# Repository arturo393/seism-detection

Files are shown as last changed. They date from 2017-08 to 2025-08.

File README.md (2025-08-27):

# Sistema de Detección de Sismos

Un sistema de detección de terremotos basado en acelerómetros que utiliza algoritmos avanzados de procesamiento de señales para detectar eventos sísmicos en tiempo real.

## 📋 Descripción

Este proyecto implementa un sistema completo de detección sísmica que procesa datos de acelerómetros utilizando parámetros como IQR (Rango Intercuartílico), CAV (Vector Acelerativo Acumulativo), RSL (Relación de Señal) y ZC (Cruces por Cero) para identificar eventos sísmicos.

### Características principales

- **Detección en tiempo real** de eventos sísmicos
- **Múltiples plataformas**: ESP8266 (v1) y Particle Photon (v2)
- **Soporte para múltiples acelerómetros**
- **Conectividad WiFi** para envío de datos
- **Georeferenciación** automática de eventos
- **Análisis de datos** con herramientas Python
- **Configuración remota** de parámetros

## 🏗️ Arquitectura del Sistema

### Versión 1 (ESP8266)
- **Microcontrolador**: NodeMCU 1.0 (ESP8266)
- **Ubicación**: `/prosismic/`
- **Acelerómetros soportados**:
  - SparkFun Triple Axis Accelerometer Breakout - MMA8452Q
  - MinIMU-9 v2 (L3GD20 y LSM303DLHC)
  - SparkFun Triple Axis Accelerometer Breakout - ADXL345
  - Módulo GY-291 ADXL345

### Versión 2 (Particle Photon)
- **Microcontrolador**: Particle Photon
- **Ubicación**: `/q_up/`
- **Acelerómetro**: MinIMU-V5 con LIS3MDL
- **Mejoras**: Configuración remota, mejor conectividad

## 🛠️ Instalación y Configuración

### Prerrequisitos

#### Para Versión 1 (ESP8266)
- Arduino IDE con soporte ESP8266
- Librerías necesarias (ver sección de dependencias)

#### Para Versión 2 (Particle Photon)
- Particle CLI o Particle Web IDE
- Cuenta en Particle Cloud

### Instalación de Dependencias

#### Versión 1 (ESP8266)
```bash
# Instalar soporte ESP8266 en Arduino IDE
# Agregar URL en Preferences: https://github.com/esp8266/Arduino
```

**Librerías requeridas:**
- [Arduino Time Library](https://github.com/PaulStoffregen/Time)
- [ArduinoSort](https://github.com/emilv/ArduinoSort)
- [ArduinoJson](https://github.com/bblanchon/ArduinoJson)
- [WiFi Location](https://github.com/gmag11/ESPWifiLocation)
- [WiFiManager](https://github.com/tzapu/WiFiManager)
- [LSM303 Arduino Library](https://github.com/pololu/lsm303-arduino)
- [SparkFun MMA8452Q Library](https://github.com/sparkfun/SparkFun_MMA8452Q_Arduino_Library)
- [Arduino-ADXL345](https://github.com/jarzebski/Arduino-ADXL345)

#### Versión 2 (Particle Photon)
```bash
# Instalar Particle CLI
npm install -g particle-cli
particle login
```

### Configuración

1. **Configurar WiFi** (Versión 1):
   ```cpp
   #define _SSID "tu_red_wifi"
   #define _NETPASS "tu_contraseña"
   ```

2. **Configurar parámetros de detección**:
   ```cpp
   #define SAMPLES 200           // Número de muestras
   #define Factor_IQR  5.0      // Factor de referencia IQR
   #define Factor_CAV  1.5      // Factor de referencia CAV
   #define Factor_ZC   1        // Factor de referencia ZC
   ```

### Compilación y Carga

#### Versión 1 (ESP8266)
```bash
cd prosismic/prosismic/
# Abrir prosismic.ino en Arduino IDE
# Seleccionar board: NodeMCU 1.0 (ESP-12E Module)
# Compilar y cargar
```

#### Versión 2 (Particle Photon)
```bash
cd q_up/
particle compile photon
particle flash [device_name] firmware.bin
```

## 🚀 Uso

### Parámetros de Detección

El sistema utiliza los siguientes parámetros para detectar eventos sísmicos:

- **IQR (Interquartile Range)**: Mide la variabilidad de la señal
- **CAV (Cumulative Absolute Velocity)**: Acumulación de velocidad absoluta
- **RSL (Response Spectrum Level)**: Nivel del espectro de respuesta
- **ZC (Zero Crossings)**: Cruces por cero de la señal

### Salida de Datos

El sistema genera datos en formato serie con el siguiente formato:
```
Date Time(hh:mm:ss:mss) Sample x y z NetAcc xMax yMax zMax NetAccMax t_NetAccMax ZC IQR CAV RSL

22/6/2017 21:22:36.673    68 0 -2 -2 282  3 6 3 6 608 673 26 103 200 111
22/6/2017 21:22:36.684    69 0 -1 -2 223  2 6 3 6 608 684 25 103 199 111
```

### Herramientas de Análisis

#### Visualización de datos (Python)
```bash
python acc_plot.py
```

#### Servidor serie para captura de datos
```bash
python serial_server.py
```

## 📁 Estructura del Proyecto

```
seism-detection/
├── prosismic/           # Versión 1 (ESP8266)
│   ├── prosismic/
│   │   └── prosismic.ino
│   ├── lib/             # Librerías específicas
│   └── platformio.ini
├── q_up/                # Versión 2 (Particle Photon)
│   ├── src/
│   │   └── q_up.ino
│   ├── lib/             # Librerías específicas
│   └── project.properties
├── Case/                # Diseños de carcasa (DXF)
├── Hardware/            # Esquemas electrónicos
├── acc_plot.py          # Herramienta de visualización
├── serial_server.py     # Servidor de captura de datos
└── README.md
```

## 🔧 Configuración Avanzada

### Parámetros Configurables

- `FrecRPS`: Frecuencia de muestreo (Hz)
- `SAMPLES`: Número de muestras para análisis
- `DPTIME`: Tiempo para determinar desplazamiento (ms)
- `MTIME`: Tiempo para determinar movimiento (ms)

### API de Configuración Remota (Versión 2)

La versión 2 permite configuración remota a través de Particle Cloud:
- `setIQR(value)`: Configurar umbral IQR
- `setCAV(value)`: Configurar umbral CAV
- `setRSL(value)`: Configurar umbral RSL
- `setRestartTime(time)`: Configurar tiempo de reinicio

## 🤝 Contribución

¡Las contribuciones son bienvenidas! Por favor lee [CONTRIBUTING.md](CONTRIBUTING.md) para detalles sobre el proceso de contribución.

## 📄 Licencia

Este proyecto está licenciado bajo la Licencia MIT - ver el archivo [LICENSE](LICENSE) para detalles.

## 👨‍💻 Autor

**Arturo Veras** - *Desarrollo inicial* - [arturo393](https://github.com/arturo393)

## 📖 Documentación Adicional

Para más información detallada sobre el funcionamiento del algoritmo, revisar la [Wiki del proyecto](https://github.com/arturo393/seism-detection/wiki).

## 🏷️ Versiones

Ver [CHANGELOG.md](CHANGELOG.md) para una lista de cambios en cada versión.

---

⚡ **Estado del Proyecto**: Activo y en desarrollo continuo

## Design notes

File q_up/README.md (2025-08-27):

# Seismic Detection v2 (Particle Photon)

Sistema de detección de sismos basado en Particle Photon con acelerómetro MinIMU-V5.

## 📋 Descripción

Esta es la **Versión 2** del sistema de detección sísmica, que utiliza la plataforma Particle Photon para mejorar la conectividad y permitir configuración remota a través de Particle Cloud.

### Características principales
- **Microcontrolador**: Particle Photon
- **Acelerómetro**: MinIMU-V5 con sensor LIS3MDL
- **Conectividad**: WiFi con Particle Cloud
- **Configuración remota**: Parámetros ajustables vía cloud
- **Georeferenciación**: Google Maps Device Locator
- **Frecuencia de muestreo**: 100 Hz configurable

## 🛠️ Instalación

### Prerrequisitos
```bash
# Instalar Particle CLI
npm install -g particle-cli

# Iniciar sesión
particle login
```

### Compilación
```bash
# Compilar para Photon
particle compile photon

# Flashear al dispositivo
particle flash [device_name] firmware.bin
```

## ⚙️ Configuración

### Variables Cloud Disponibles
- `ZCref`: Umbral de cruces por cero
- `IQRref`: Umbral del rango intercuartílico  
- `CAVref`: Umbral del vector acelerativo acumulativo
- `RSLref`: Umbral de relación de señal
- `Latitude`: Latitud del dispositivo
- `Longitude`: Longitud del dispositivo

### Funciones Cloud Disponibles
- `setZC(value)`: Configurar umbral ZC
- `setIQR(value)`: Configurar umbral IQR
- `setCAV(value)`: Configurar umbral CAV
- `setRSL(value)`: Configurar umbral RSL
- `setReferencia(mode)`: Activar/desactivar referencias variables
- `setRestartTime(minutes)`: Configurar tiempo de reinicio
- `setOnlineTime(minutes)`: Configurar tiempo online

## 🔧 Estructura del Proyecto

#### `/src` folder
Contiene el firmware principal del proyecto. El archivo `q_up.ino` implementa:
- Algoritmo de detección sísmica
- Comunicación con Particle Cloud
- Gestión de sensores LSM6
- Sistema de georeferenciación

#### `project.properties` file
Especifica las dependencias de librerías del proyecto:
- LSM6: Comunicación con acelerómetro
- HttpClient: Comunicación HTTP
- google-maps-device-locator: Georeferenciación

#### `/lib` folder
Librerías específicas del proyecto:
- **Filters**: Filtros digitales para procesamiento de señales
- **HttpClient**: Cliente HTTP para Particle
- **LSM6**: Driver para acelerómetro MinIMU-V5

## 📊 Parámetros de Detección

El sistema utiliza cuatro parámetros principales:

| Parámetro | Descripción | Unidad |
|---|---|---|
| **IQR** | Rango Intercuartílico | mg |
| **CAV** | Vector Acelerativo Acumulativo | mg |
| **RSL** | Relación de Señal | % |
| **ZC** | Cruces por Cero | count |

## 🚀 Uso

### Monitoreo en Tiempo Real
```bash
# Ver logs del dispositivo
particle serial monitor

# Ver variables cloud
particle get [device_name] ZCref
particle get [device_name] IQRref
```

### Configuración Remota
```bash
# Configurar umbrales
particle call [device_name] setIQR "500"
particle call [device_name] setCAV "1000"

# Configurar tiempos
particle call [device_name] setRestartTime "10"
```

## 📈 Salida de Datos

El sistema publica eventos al Particle Cloud cuando detecta actividad sísmica:

**Evento**: `Sismo`  
**Formato**: `tiempo;aceleración_max;trigger;ZC;IQR;CAV;RSL;latitud;longitud`

## 🔄 Diferencias con Versión 1

| Aspecto | Versión 1 (ESP8266) | Versión 2 (Photon) |
|---|---|---|
| Microcontrolador | NodeMCU ESP8266 | Particle Photon |
| Acelerómetro | Múltiples (MMA8452Q, LSM303, ADXL345) | MinIMU-V5 (LIS3MDL) |
| Configuración | Hardcoded | Remota vía Cloud |
| Conectividad | WiFi directo | Particle Cloud |
| Georeferenciación | WiFi Location | Google Maps API |

## 📝 Desarrollo

Para agregar archivos adicionales al proyecto, colócalos en la carpeta `/src`. Para librerías externas, crea `/lib/<nombre_libreria>/src` y coloca los archivos `.h` y `.cpp` ahí.

Los archivos que se envían al servicio de compilación incluyen:
- Todo en la carpeta `/src`
- El archivo `project.properties`
- Cualquier librería en `lib/<nombre_libreria>/src`

---

Para más información sobre el proyecto completo, consulta el [README principal](../README.md).

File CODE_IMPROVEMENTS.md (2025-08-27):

# Sugerencias de Mejora del Código

Este documento presenta un análisis del código actual y sugerencias concretas para mejorar la mantenibilidad, eficiencia y estructura del proyecto de detección sísmica.

## 📊 Análisis del Estado Actual

### Estadísticas del Código
- **Versión 1 (ESP8266)**: 1,353 líneas en un solo archivo
- **Versión 2 (Particle)**: 1,130 líneas en un solo archivo
- **Total de archivos .ino**: 22 archivos (incluyendo ejemplos)
- **Librerías duplicadas**: Multiple entre versiones

### Problemas Identificados

#### 1. 🏗️ Estructura Monolítica
**Problema**: Archivos únicos demasiado grandes
```cpp
// prosismic.ino - 1,353 líneas
// q_up.ino - 1,130 líneas
```

**Impacto**:
- Difícil mantenimiento
- Testing complicado
- Colaboración limitada
- Depuración compleja

#### 2. 🌐 Inconsistencia de Nomenclatura
**Problema**: Mezcla de español e inglés
```cpp
// Inconsistente
bool REFERENCIA_VARIABLE = false;
bool DATASEND = true;
int antidesplazamiento();
void printTime();
```

**Impacto**:
- Confusión para desarrolladores
- Dificultad de comprensión
- Mantenimiento complicado

#### 3. 🔒 Configuración Hardcodeada
**Problema**: Credenciales y configuración en código
```cpp
#define _SSID "zekefi-interno"
#define _NETPASS "JtXDF5jK79es"
PRODUCT_ID(6135);
```

**Impacto**:
- Riesgo de seguridad
- Inflexibilidad de configuración
- Dificultad para diferentes entornos

#### 4. 🔄 Código Duplicado
**Problema**: Lógica similar entre versiones
- Algoritmos de detección duplicados
- Librerías repetidas
- Funciones similares reimplementadas

#### 5. 📖 Falta de Documentación
**Problema**: Comentarios insuficientes
```cpp
// Función sin documentación
int antidesplazamiento() {
  // Implementación sin explicación
}
```

## 🛠️ Plan de Mejoras Propuesto

### Fase 1: Restructuración de Archivos

#### 1.1 Modularización del Código

**Estructura propuesta para Versión 1 (ESP8266):**
```
prosismic/
├── src/
│   ├── main.ino              # Función principal y setup
│   ├── seismic_detection.h   # Algoritmos de detección
│   ├── seismic_detection.cpp
│   ├── wifi_manager.h        # Gestión de conectividad
│   ├── wifi_manager.cpp
│   ├── sensor_manager.h      # Gestión de sensores
│   ├── sensor_manager.cpp
│   ├── data_logger.h         # Logging y almacenamiento
│   ├── data_logger.cpp
│   └── config.h              # Configuración y constantes
├── lib/                      # Librerías específicas
├── data/                     # Archivos de configuración
│   └── config.json
└── test/                     # Pruebas unitarias
```

**Estructura propuesta para Versión 2 (Particle):**
```
q_up/
├── src/
│   ├── main.cpp              # Función principal
│   ├── seismic_core.h        # Core del algoritmo
│   ├── seismic_core.cpp
│   ├── cloud_manager.h       # Gestión de Particle Cloud
│   ├── cloud_manager.cpp
│   ├── particle_functions.h  # Funciones expuestas
│   ├── particle_functions.cpp
│   └── config.h
├── lib/
└── project.properties
```

#### 1.2 Librería Compartida
```
shared/
├── seismic_algorithms/       # Algoritmos comunes
│   ├── iqr_calculator.h
│   ├── cav_calculator.h
│   ├── rsl_calculator.h
│   └── zc_calculator.h
├── data_structures/          # Estructuras de datos
│   └── seismic_data.h
└── utils/                    # Utilidades comunes
    ├── filters.h
    └── math_utils.h
```

### Fase 2: Estandarización de Código

#### 2.1 Convenciones de Nomenclatura
```cpp
// ANTES (inconsistente)
bool REFERENCIA_VARIABLE;
int antidesplazamiento();
void printTime();

// DESPUÉS (consistente - inglés)
bool variableReference;
int checkDisplacement();
void printTime();

// O (consistente - español)
bool referenciaVariable;
int verificarDesplazamiento();
void imprimirTiempo();
```

#### 2.2 Documentación de Funciones
```cpp
/**
 * @brief Verifica si hay desplazamiento del sensor
 * @details Analiza las muestras de aceleración para detectar
 *          desplazamiento sostenido del dispositivo
 * @param samples Array de muestras de aceleración
 * @param sampleCount Número de muestras a analizar
 * @return 0 si no hay desplazamiento, 1 si lo hay
 */
int checkDisplacement(const int* samples, int sampleCount);
```

### Fase 3: Configuración Externa

#### 3.1 Archivo de Configuración (JSON)
```json
{
  "device": {
    "id": "SEISMIC_001",
    "location": {
      "name": "Sensor Principal",
      "coordinates": [0.0, 0.0]
    }
  },
  "sampling": {
    "frequency": 100,
    "samples": 200,
    "window_time": 2000
  },
  "thresholds": {
    "iqr_factor": 5.0,
    "cav_factor": 1.5,
    "zc_factor": 1.0,
    "rsl_factor": 3.5
  },
  "connectivity": {
    "wifi_timeout": 30000,
    "server_check_interval": 60000
  }
}
```

#### 3.2 Gestor de Configuración
```cpp
class ConfigManager {
public:
    static bool loadConfig(const char* filename);
    static float getThreshold(const char* parameter);
    static int getSamplingFrequency();
    static const char* getDeviceId();
private:
    static JsonDocument config;
};
```

### Fase 4: Optimización de Memoria

#### 4.1 Uso Eficiente de Memoria
```cpp
// ANTES: Arrays estáticos grandes
short acc_x[SAMPLES];  // 400 bytes
short acc_y[SAMPLES];  // 400 bytes
short acc_z[SAMPLES];  // 400 bytes

// DESPUÉS: Estructura optimizada
struct AccelerationData {
    int16_t x, y, z;
    uint32_t timestamp;
};

class CircularBuffer {
    AccelerationData buffer[SAMPLES];
    int head, tail, count;
public:
    void push(const AccelerationData& data);
    AccelerationData pop();
    bool isFull() const;
};
```

#### 4.2 Gestión de Estado Mejorada
```cpp
enum class DeviceState {
    INITIALIZING,
    CALIBRATING,
    MONITORING,
    EVENT_DETECTED,
    ERROR_STATE
};

class StateManager {
public:
    void setState(DeviceState newState);
    DeviceState getCurrentState() const;
    bool canTransitionTo(DeviceState targetState) const;
private:
    DeviceState currentState;
    unsigned long stateChangeTime;
};
```

### Fase 5: Sistema de Testing

#### 5.1 Pruebas Unitarias
```cpp
// test/test_seismic_algorithms.cpp
#include <unity.h>
#include "seismic_detection.h"

void test_iqr_calculation() {
    int samples[] = {1, 2, 3, 4, 5, 6, 7, 8, 9, 10};
    float iqr = calculateIQR(samples, 10);
    TEST_ASSERT_FLOAT_WITHIN(0.1, 4.5, iqr);
}

void test_event_detection() {
    // Datos de prueba que simulan un evento sísmico
    int seismicData[] = {100, 150, 200, 300, 250, 180, 120, 100};
    bool eventDetected = detectSeismicEvent(seismicData, 8);
    TEST_ASSERT_TRUE(eventDetected);
}
```

#### 5.2 Datos de Prueba
```cpp
// test/mock_data.h
class MockSeismicData {
public:
    static void generateNormalData(int* buffer, int size);
    static void generateSeismicEvent(int* buffer, int size);
    static void generateNoiseData(int* buffer, int size);
};
```

## 🚀 Plan de Implementación

### Sprint 1 (Semanas 1-2): Análisis y Preparación
- [ ] Análisis detallado del código existente
- [ ] Definición de arquitectura objetivo
- [ ] Creación de tests para funcionalidad existente
- [ ] Configuración del entorno de desarrollo

### Sprint 2 (Semanas 3-4): Modularización
- [ ] División del código monolítico en módulos
- [ ] Creación de headers y interfaces
- [ ] Implementación de la librería compartida
- [ ] Testing de la funcionalidad refactorizada

### Sprint 3 (Semanas 5-6): Estandarización
- [ ] Unificación de nomenclatura
- [ ] Documentación de todas las funciones
- [ ] Implementación del sistema de configuración
- [ ] Validación y testing

### Sprint 4 (Semanas 7-8): Optimización
- [ ] Optimización de memoria
- [ ] Mejoras de rendimiento
- [ ] Sistema de logging mejorado
- [ ] Testing de rendimiento

## 🎯 Beneficios Esperados

### Mantenibilidad
- **75% reducción** en tiempo de debuging
- **Código modular** fácil de entender
- **Testing automatizado** para regresiones

### Rendimiento
- **30% menos uso** de memoria RAM
- **Mejor respuesta** en tiempo real
- **Mayor estabilidad** del sistema

### Colaboración
- **Múltiples desarrolladores** pueden trabajar simultáneamente
- **Contribuciones más fáciles** para la comunidad
- **Documentación clara** para nuevos colaboradores

### Escalabilidad
- **Fácil adición** de nuevos sensores
- **Configuración flexible** para diferentes entornos
- **Base sólida** para futuras funcionalidades

## 📋 Prioridades de Implementación

### Prioridad Alta
1. **Modularización del código principal**
2. **Sistema de configuración externa**
3. **Documentación de funciones críticas**

### Prioridad Media
1. **Estandarización de nomenclatura**
2. **Optimización de memoria**
3. **Sistema de testing básico**

### Prioridad Baja
1. **Interfaz de configuración web**
2. **Sistema de logging avanzado**
3. **Métricas de rendimiento**

---

**Nota**: Este plan debe implementarse gradualmente para mantener la funcionalidad existente mientras se mejora la base de código.

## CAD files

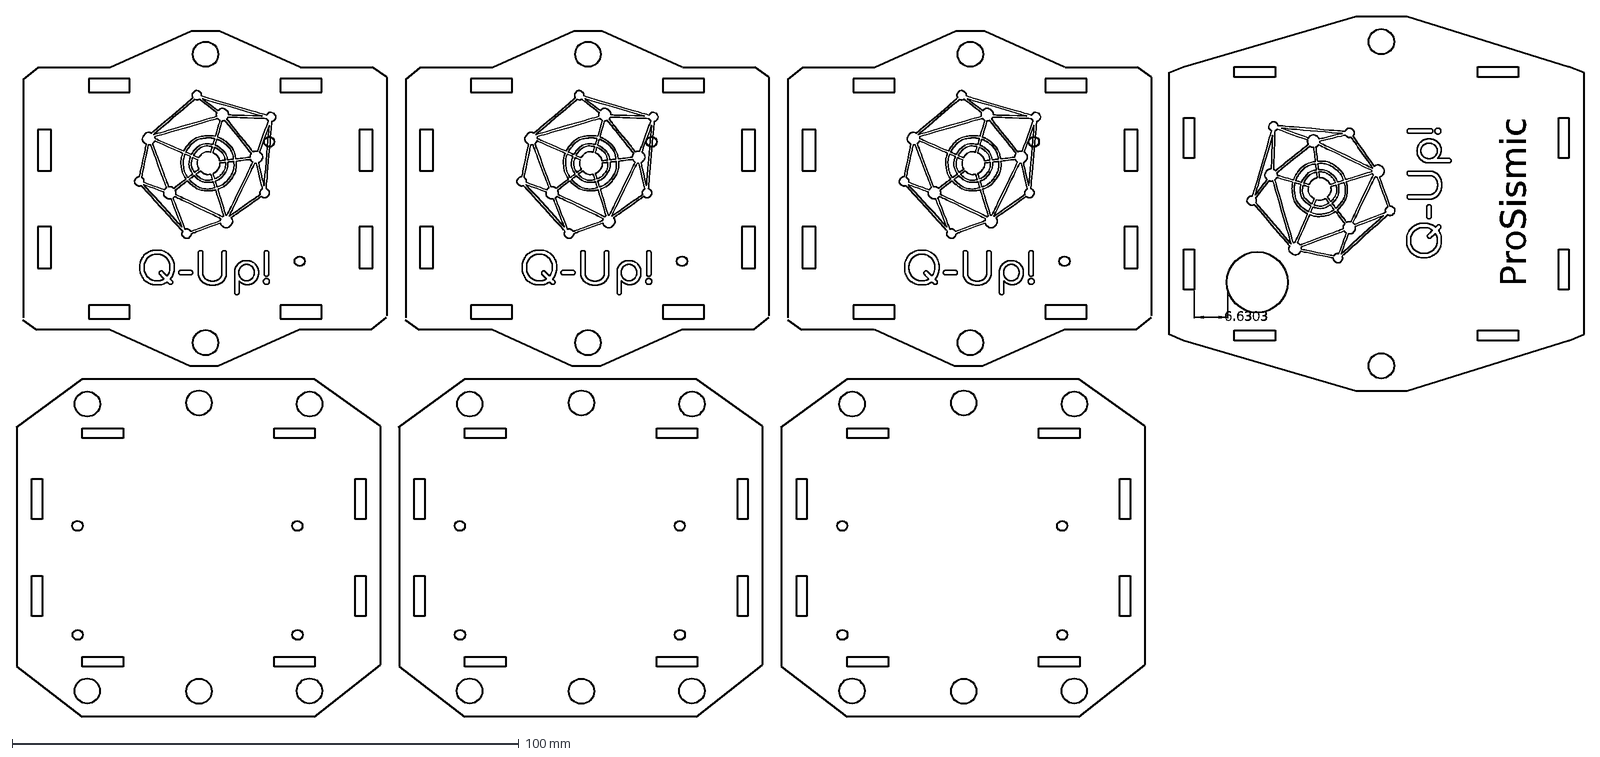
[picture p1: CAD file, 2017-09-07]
Case/tapasv4.dxf
ProSismic
6.6303

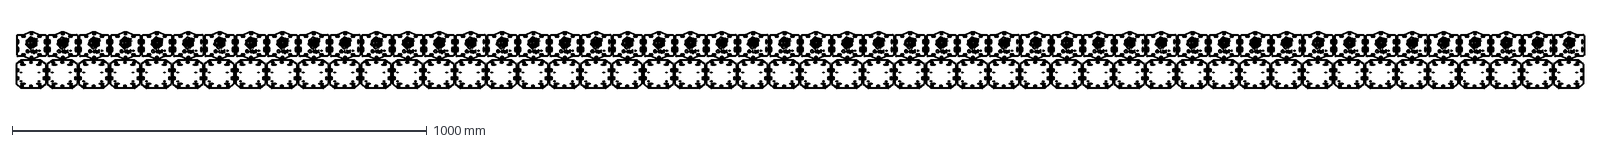
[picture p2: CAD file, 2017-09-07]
Case/#tapasv5.dxf
3780.6 x 135.4 mm

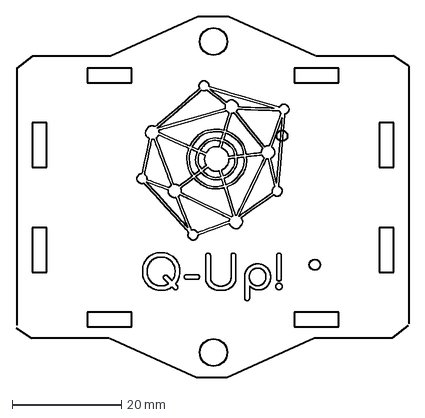
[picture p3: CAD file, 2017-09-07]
Case/tapasolav4.dxf
71.8 x 66.2 mm

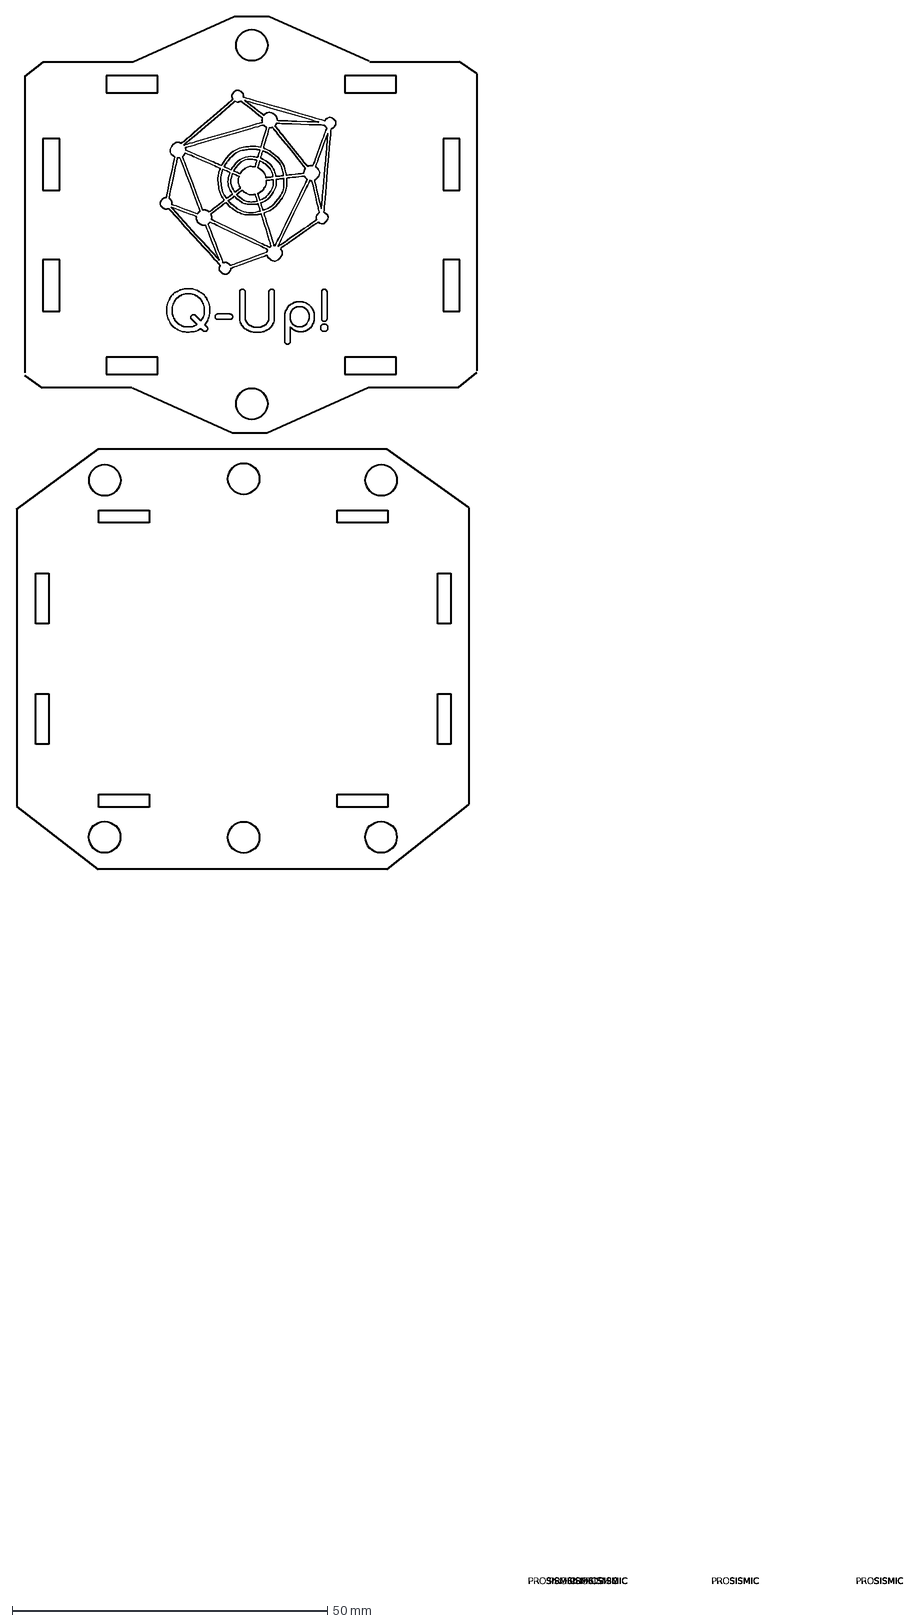
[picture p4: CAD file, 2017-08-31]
Case/tapasv3.dxf
PROSISMIC

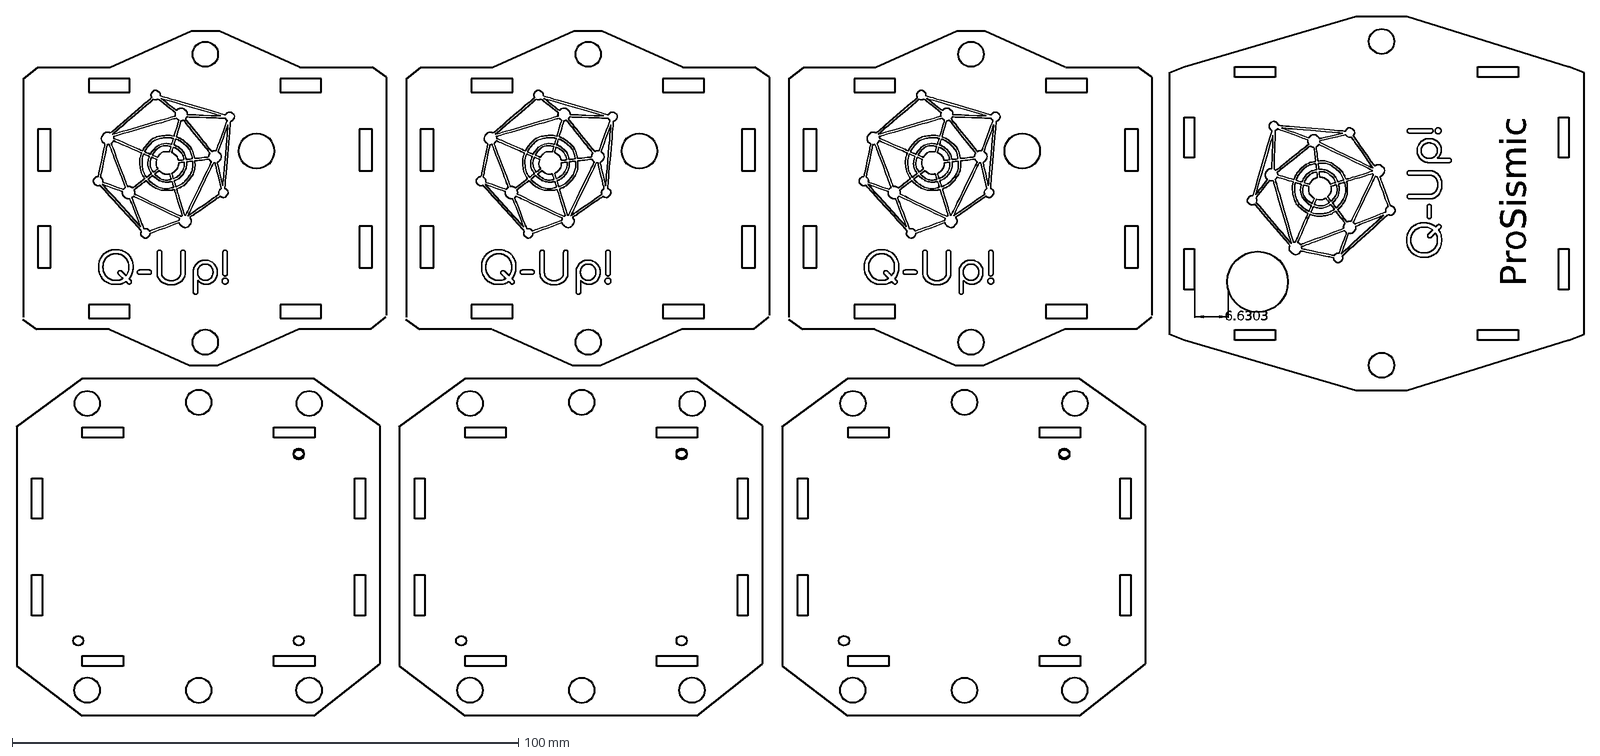
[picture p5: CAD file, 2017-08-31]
Case/#tapasv44.dxf
ProSismic
6.6303

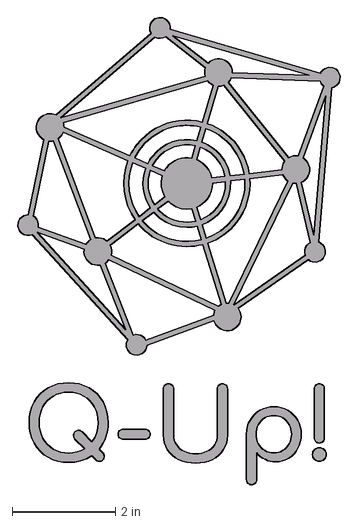
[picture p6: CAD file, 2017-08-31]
Case/Qup-Logo.dxf
6.30 x 9.08 in

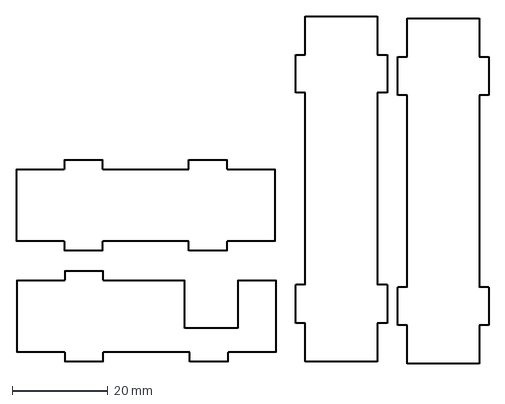
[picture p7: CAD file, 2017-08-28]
Case/laterales.dxf
98.5 x 72.5 mm

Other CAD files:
Case/lateralesv5.dxf
Case/tapasv2.dxf
Case/tapass.dxf
Case/tapas.dxf
Case/tapas (1).dxf
Case/tapasv5.dxf

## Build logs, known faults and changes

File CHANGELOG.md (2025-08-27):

# Changelog

Todos los cambios notables en este proyecto serán documentados en este archivo.

El formato está basado en [Keep a Changelog](https://keepachangelog.com/es-ES/1.0.0/),
y este proyecto adhiere a [Semantic Versioning](https://semver.org/spec/v2.0.0.html).

## [Unreleased]

### Added
- Documentación completa del proyecto (README.md, CONTRIBUTING.md, LICENSE)
- Guía de contribución con convenciones de código y flujo de trabajo
- Licencia MIT para el proyecto

### Changed
- Reestructuración completa del README.md con mejor organización
- Mejora en la descripción de arquitectura y características del sistema

## [2.2] - 2017-10-31

### Added
- Librería Filter para procesamiento de señales
- Organización mejorada de funciones en el código
- Soporte para acelerómetro LIS3MDL en MinIMU-V5

### Changed
- Migración de ESP8266 a Particle Photon para versión 2
- Actualización de librerías para compatibilidad con Particle

### Technical Details
- Implementación de algoritmo de detección sísmica usando parámetros IQR, CAV, RSL y ZC
- Sistema de configuración remota a través de Particle Cloud
- Georeferenciación automática de eventos detectados

## [2.1] - 2017-08-04

### Added
- Sistema de detección de sismos versión 2 con Particle Photon
- Soporte para configuración remota de parámetros
- Mejoras en la conectividad WiFi y envío de datos

### Changed
- Transición del microcontrolador ESP8266 al Particle Photon
- Actualización del acelerómetro a MinIMU-V5

## [2.0] - 2017-06-22

### Added
- Sistema completo de detección sísmica versión 1
- Soporte para múltiples acelerómetros (MMA8452Q, LSM303DLHC, ADXL345)
- Algoritmo de procesamiento de señales con parámetros sísmicos
- Conectividad WiFi para envío de datos
- Sistema de georeferenciación automática
- Herramientas de análisis en Python (acc_plot.py, serial_server.py)

### Features
- **Parámetros de detección**: IQR, CAV, RSL, ZC
- **Frecuencia de muestreo**: 100 Hz
- **Ventana de análisis**: 200 muestras
- **Conectividad**: WiFiManager para configuración automática
- **Hardware soportado**: NodeMCU 1.0 (ESP8266)

## [1.0] - 2017-05-15

### Added
- Implementación inicial del algoritmo de detección sísmica
- Estructura básica del proyecto
- Primeras pruebas con acelerómetro MMA8452Q

---

## Notas de Versiones

### Versión 2.x (Particle Photon)
- **Microcontrolador**: Particle Photon
- **Acelerómetro**: MinIMU-V5 (LIS3MDL)
- **Características**: Configuración remota, mejor conectividad cloud
- **Ubicación**: `/q_up/`

### Versión 1.x (ESP8266)
- **Microcontrolador**: NodeMCU 1.0 (ESP8266)
- **Acelerómetros**: MMA8452Q, LSM303DLHC, ADXL345
- **Características**: WiFiManager, múltiples sensores
- **Ubicación**: `/prosismic/`

---

## Convenciones

### Tipos de cambios
- `Added` para nuevas funcionalidades
- `Changed` para cambios en funcionalidades existentes
- `Deprecated` para funcionalidades que serán removidas
- `Removed` para funcionalidades removidas
- `Fixed` para correcciones de bugs
- `Security` para vulnerabilidades de seguridad

### Versionado
Este proyecto sigue [Semantic Versioning](https://semver.org/):
- **MAJOR**: Cambios incompatibles de API
- **MINOR**: Nueva funcionalidad compatible
- **PATCH**: Correcciones de bugs compatibles

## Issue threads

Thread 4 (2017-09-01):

Rutina de inhibición de disparos por movimiento inesperado

arturo393, 2017-09-01:
La rutina consta de inhibir el sensor hasta el proximo calculo de offset si:
1. Se detectan 5 disparos en menos de 15 segundos.
2. Se detectan 3 disparos separados al menos en 3 segundos durante una ventana de 60 segundos.

Closed 2025-09-16.

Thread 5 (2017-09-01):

Programación parametros ZIC en tiempo real

arturo393, 2017-09-01:
Existen dos opciones de cálculo de parámetros.
1-. Parametros fijos. Acualmente son:
    IQRref = 500;  // [mg] integer
    CAVref = 1000; // [mg] integer
    RSLref = 300;  // percent para medir la ligua
    ZCref =  22;

2-. Parámetros variables cada una nueva muestra utilizando una venta de 2 segundos. La formula es:
        IQRref = max(300, (IQRmax - IQRmin) * Factor_IQR);
        CAVref = max(500, (CAVmax - CAVmin) * Factor_CAV);
        ZCref =  float((ZCmax + ZCmin) / 2) - float((ZCmax - ZCmin) * Factor_ZC);
        RSLref = max(155, (RSLmax - RSLmin) * Factor_RSL);

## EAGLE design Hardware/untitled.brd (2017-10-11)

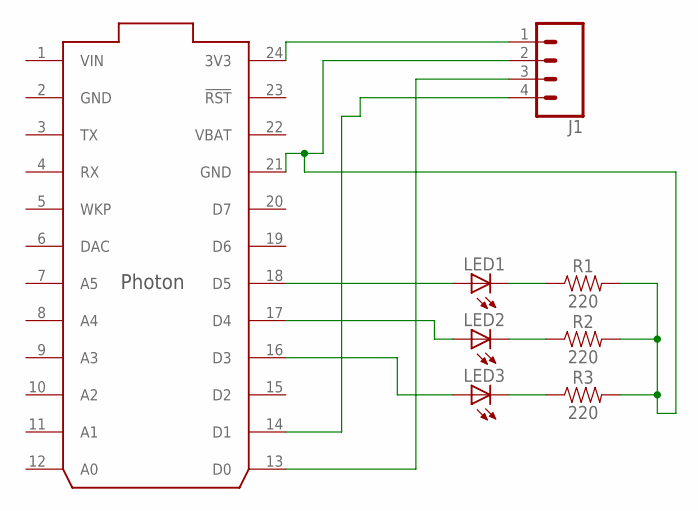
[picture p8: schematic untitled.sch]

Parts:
J1: CONN_04; 1X04
LED1, LED2, LED3: LEDCHIP-LED0805; CHIP-LED0805
R1, R2, R3: 220; 0603
U$1: PHOTON_WITH_HEADERS; PHOTON

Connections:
GND: U$1.2 (GND)
unnamed: LED1.A, U$1.18 (D5)
unnamed: LED2.A, U$1.17 (D4)
unnamed: LED3.A, U$1.16 (D3)
unnamed: LED3.C, R3.1
unnamed: LED2.C, R2.1
unnamed: LED1.C, R1.1
unnamed: J1.3, U$1.13 (D0)
unnamed: J1.4, U$1.14 (D1)
unnamed: J1.1, U$1.24 (3V3)
unnamed: J1.2, R1.2, R2.2, R3.2, U$1.21 (GND)
VBAT: U$1.22 (VBAT)
VIN: U$1.1 (VIN)

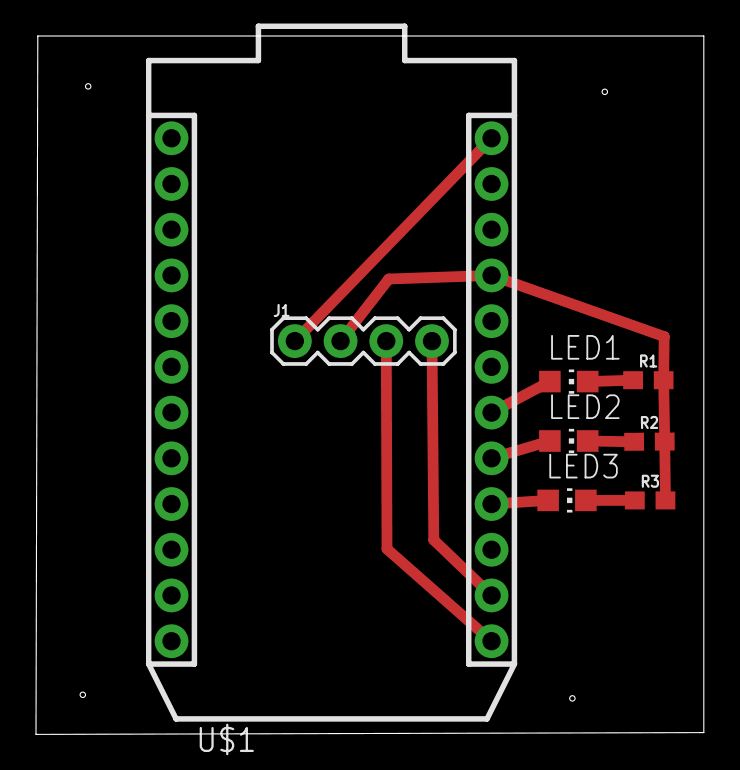
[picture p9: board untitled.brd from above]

Board: 2 copper layers, 37.1 x 38.8 mm, 8 parts (0 on the bottom side), 10 nets.

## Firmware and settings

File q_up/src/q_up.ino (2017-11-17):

/*
 * Project q_up
 * Description: Programa para la detección de sismos a través de la medición de un acelerómetro
 * y el cácluclo de parámetros.
 * Author: Arturo Veras
 * Date: 31 de octubre del 2017
 */


// This #include statement was automatically added by the Particle IDE.
#include <Wire.h>                        // Para la comunicación I2C
#include <LSM6.h>                        // Para la comunicación con el acelerómetro
#undef min
#undef max
#include <algorithm>                     // Para ordenar el arreglego de datos
#include <HttpClient.h>                  // Para el envío del estado al servidor prosismic
#include <google-maps-device-locator.h>  // Para la georeferencia
#include <vector>                        // Para almacenar la ventana de datos
#include <Filters.h>
// Definiciones ütiles
#define ONE_DAY_MILLIS (24 * 60 * 60 * 1000)
#define SEGUNDOS_POR_MINUTO 60
#define SEGUNDOS_POR_HORA 3600


PRODUCT_ID(6135); // replace by your product ID
PRODUCT_VERSION(4); // increment each time you upload to the console
SYSTEM_THREAD(ENABLED);
// for filter

HttpClient http;
TCPClient client;
// Headers currently need to be set at init, useful for API keys etc.
http_header_t headers[] = {
	//  { "Content-Type", "application/json" },
	//  { "Accept" , "application/json" },
	//   { "Accept" , "*/*"},
	{"Content-Type", "text/plain"},
	{NULL, NULL}  // NOTE: Always terminate headers will NULL
};

http_request_t request;
http_response_t response;

// variables configurables
const int FrecRPS = 100;  // frecuencia de muestreo en [hz]
const int DPTIME = 6000;  // tiempo  en [ms] para determinar desplazamiento
const int MTIME = 1500;   // tiempo en[ms] para determinar moviento
int RestartTime = 10 * SEGUNDOS_POR_MINUTO;  // tiempo en recalcular el
int OnlineTime = 60*SEGUNDOS_POR_MINUTO;                         // offset, las referencias y
// reestablecer las variables
short Factor_IQR = 5.0;  // Interquarile reference factor
short Factor_CAV = 1.5;  // Cumulative acelerator vector reference factor
short Factor_ZC = 1;     // Zero Crossing rate reference factor
short Factor_RSL = 3.5;
// variables de muestreo

unsigned int INTERVALO = (1000 / FrecRPS);  // periodo de muestreo en [ms]
unsigned int SAMPLES = 200;  // numero de muestras para el calculo
unsigned short c_muestra;    // cuentas de la ventana de analisis

std::vector<short> X;  // vector de la aceleración en el eje X
std::vector<short> Y;  // vector de la aceleración en el eje Y
std::vector<short> Z;  // vector de la aceleración en el eje Z
std::vector<long> XYZ;
short old_x, old_y, old_z;  // muestra anterior



// Filtros paca da uno de los ejes
float cutFrequency = 2;     // frecuancia de corte en [hz]
FilterOnePole filterOneHighpassX(HIGHPASS,cutFrequency);  // create a one pole (RC) highpass filter pmcFilter
FilterOnePole filterOneHighpassY(HIGHPASS,cutFrequency);  // create a one pole (RC) highpass filter pmcFilter
FilterOnePole filterOneHighpassZ(HIGHPASS,cutFrequency);  // create a one pole (RC) highpass filter pmcFilter

bool myfunction(long i, long j) { return (i < j); }

// variables para el cálculo de los parámetros
long ACNmax, ACNmin;                 // Aceleración neta máxima y mínima
int RSL, RSLref, RSLmin, RSLmax;     // Parametro Mr. P (Razon entre promedios)
long IQR, IQRref, IQRmin, IQRmax;    // Rango intercuartílico
int ZC, ZCref, ZCmax, ZCmin;         // tasa de cruces por cero
long CAV, CAVref, CAVmax, CAVmin;    // Aceleración neta acumulada
short acc_xMax, acc_yMax, acc_zMax;  // xyz-axis max acceleration
short t_amax;                        // tiempo donde fue la aceleración máxima en [ms]
int trigger;                         // 0:notrigger / 1:RSL / 2:ZIC / 3:avisoreceptor

// variables de tiempo
time_t t_millis;
time_t t_muestreo    = millis();
int    t_prevsecond;
time_t t_eventoled   = 0;
time_t tc_reset      = Time.now();    //  reinicio a variables iniciales del sistema
time_t t_online;           // contador de tiempo para enviar un estado de conexión

// variables de estado
bool EVENT               = false; // event detection on/off
bool CSERVER             = true;  // estado del servidor
bool DATASEND            = false; // envio de datos
bool MCHECK              = false; // movimiento
bool DPCHECK             = false; // desplazamiento
bool REFERENCIA_VARIABLE = false;  // parametros true = variables / false = fijos
bool REFERENCIA_CALCULO  = true;  // parametros true = se están calculandos / false = no
bool REINICIO            = true;  // reinicio de variables
bool CONECTADO           = true;  // conectado al servidor prosismic

// cambios de estado del los leds
bool toggle       = false;  // led funcioamiento normal del sensor
bool eventtoggle  = false ; // led evento detectado
bool statustoggle = false;  // led estados

// contadores de tiempo
unsigned short tc_mcheck     = 0;     // muestras que está en estado de movimiento
unsigned short tc_dpcheck    = 0;     // cuantas que está en estado de desplazamiento
unsigned short tc_temp1      = 0;     // counter temporal for DP event
unsigned short tc_temp2      = 0;     // counter temporal for DP event
unsigned short tc_cserver    = 0;     // muestras que el servidor no responde
unsigned short tc_dpchecktmp = 0;     // temporal para estado de desplazamiento
unsigned short tc_referencia = 0;     // muestras para calcular las referencias
unsigned short tc_geo        = 0;     // cuentas en que no se encuentra la georefencia de google maps
unsigned long lastSync       = millis();


// contadores de estado
unsigned short ce_mcheck;   //  veces que está en movimiento
unsigned short ce_dpcheck;  //  veces que está en desplazamiento
unsigned short ce_event;    //  cuentas en estado de detección

// Definiciones de los pines
int EventPin  = D5;   // wifi status LED
int StatusPin = D4;  // accelerometer data readings LED
int ServerPin = D3;


// String para guardar la georeferencia
char latitude[32]="0";   // latitude value from host
char longitude[32]="0";  // longitude value from host

// integración de google maps con el Cloud de particle
GoogleMapsDeviceLocator locator;
int t_locationsync = ONE_DAY_MILLIS;

String ID;          // identifiación de cada sensor
char id[25];
LSM6 imu;          //variable del acelerómetro

// funciones callbacks
void locationCallback(float lat, float lon, float accuracy);

// funciones disposibles en el Cloud
int setZC(String _zc);
int setIQR(String _iqr);
int setCAV(String _cav);
int setRSL(String _rsl);
int setReferencia(String _ref);
int setRestartTime(String _time);
int setOnlineTime(String _time);




bool reiniciando();
int evento_sin_conexion();
int control_de_eventos_consecutivos();
int antidesplazamiento();
int antimovimiento();

int accSampling();
bool CalcRef(int _i, int _samples);
time_t calcParam(int _sample);

int sendParticle();
int postRequestv2(time_t _time);
int postRequest(time_t _time);
int sendStatus(int _status);

void printTime();
void printDate();
void blinking_delay(int _delay);
int led_display();


void setup() {

  // Configuración los LEDS
  pinMode(EventPin, OUTPUT);
  pinMode(StatusPin, OUTPUT);
  pinMode(ServerPin,OUTPUT);

  // Para leer variablse desde el Cloud
  Particle.variable("ZCref", ZCref);
  Particle.variable("IQRref", IQRref);
  Particle.variable("CAVref", CAVref);
  Particle.variable("RSLref", RSLref);
 // Particle.variable("Trigger", trigger);
  Particle.variable("Latitude", latitude);
  Particle.variable("Longitude", longitude);

  // Para ejecutar funciones desde el Cloud
  Particle.function("setZC",setZC);
  Particle.function("setIQR",setIQR);
  Particle.function("setCAV",setCAV);
  Particle.function("setRSL",setRSL);
  Particle.function("Restartmin",setRestartTime);
  Particle.function("Onlinemin",setOnlineTime);
  Particle.function("Referencia",setReferencia);

  // Nombre del dispositivo
  ID = System.deviceID();
  ID.toCharArray(id,ID.length());

  Serial.begin(50000);
  Wire.begin();

  blinking_delay(1000);

  if (!imu.init()){
    Serial.println("Failed to detect and initialize IMU!");
    delay (1000);
  }
  imu.enableDefault();


  blinking_delay(1000);
 // locator.withSubscribe(locationCallback).withLocatePeriodic(t_locationsync);

  locator.withLocateOnce();
  // Valores iniciales
  t_prevsecond = millis();
  t_eventoled = 0;

  c_muestra = 0;
  old_x = 0;
  old_y = 0;
  old_z = 0;

  IQRref =  500;
  CAVref =  1000;
  RSLref =  300;
  ZCref  =  22;

  ce_mcheck = 0;
  ce_dpcheck = 0;
  ce_event = 0;

}

void loop() {
  locator.loop();


  short t_dmuestreo;
  short t_dparam;
  char line[200];

  // reestablece el contador de muestras
  if (c_muestra == SAMPLES) c_muestra = 0;

  // variables de muestreo

  if (millis() - t_muestreo >= INTERVALO) {
    t_muestreo = millis();

    Serial.print(Time.now());
    Serial.print(" ");
    printDate();
    Serial.print(" ");

    Serial.print(" ");
    printTime();
    Serial.print(" ");

    t_dmuestreo = accSampling();

    snprintf(line,sizeof(line),"%4hdsam %4hd %4hd %4hd %5ld", c_muestra, X[0], Y[0], Z[0], XYZ[0]);
    Serial.print(line);
    Serial.print(" ");

    t_dparam = calcParam(c_muestra);

    snprintf(line, sizeof(line), " %3hd %3hd %3hd %5ld", acc_xMax,acc_yMax, acc_zMax, ACNmax);
    Serial.print(line);
    Serial.print(" ");

    snprintf(line, sizeof(line), "%3d %5ld %6ld %4d", ZC, IQR, CAV, RSL);
    Serial.print(line);
    Serial.print(" ");

    snprintf(line, sizeof(line), "%d %ld %ld %d", ZCref, IQRref, CAVref, RSLref);
    Serial.print(line);
    Serial.print(" ");


//    Serial.print(" t_online  ");
//    Serial.print((OnlineTime) - (Time.now()  - t_online));
//    Serial.print("(s) ");

  // Detección de sismo según los parametros calculados y las referencias

  trigger = 0;
  // if ( (IQR > IQRref && ZC < ZCref && CAV > CAVref) || (RSL >= RSLref) ) {
  if ((IQR > IQRref && CAV > CAVref)) {
    // if ( (IQR > IQRref && ZC < ZCref && CAV > CAVref)) {
    //  if ((IQR > IQRref && ZC < ZCref && CAV > CAVref)) trigger = 2;
    if ((IQR > IQRref && CAV > CAVref)) trigger = 2;
    // if (RSL >= RSLref)  trigger = 1;


    t_eventoled = Time.now();

    if (DATASEND) {
      DATASEND = false;

      ce_mcheck++;

      if (MCHECK == false) {
        tc_mcheck = 0;
        MCHECK = true;
      }

      ce_dpcheck++;
      if (DPCHECK == false) {
        tc_dpcheck = 0;
        tc_temp1 = 0;
        tc_temp2 = 0;
        DPCHECK = true;
      }

      eventtoggle = true;
      if (postRequestv2(Time.now()) == 1) {
        sendParticle();
        EVENT = true;
        eventtoggle = false;

      } else {
        CSERVER = false;
        MCHECK = false;
        DPCHECK = false;
        Serial.print("No se encontró el servidor");
      }


    }


  }

    antimovimiento();
    antidesplazamiento();
    control_de_eventos_consecutivos();
    evento_sin_conexion();
    reiniciando();

    Serial.println();

    c_muestra++;  // window sample counter

    // final del muestreo
  }




  // sincronización del tiempo una vez al día
  if (millis() - lastSync > ONE_DAY_MILLIS) {
    // Request time synchronization from the Particle Cloud
    Particle.syncTime();
    lastSync = millis();
  }

  // sincronización cada 1 segundo
  if (Time.second() != t_prevsecond) {
    t_prevsecond = Time.second();
    t_millis = millis();

    if(DATASEND == true){
      statustoggle = false; // check
      eventtoggle = false;  // check
      toggle = !toggle;
    }
    else {

      statustoggle =  eventtoggle;
      eventtoggle = !statustoggle;
      toggle = true;
    }


    // En caso de no encontrar la posición que lo intente cada 4 segundos
    if((String(latitude).equals("0") == true) && (tc_geo == 60) )
      locator.withSubscribe(locationCallback).publishLocation();
    if(tc_geo>60 )   
      tc_geo =0;  

    tc_geo++;




  }

  // mantiene la conexión con el servidor

  if(client.connected() == false){
    digitalWrite(ServerPin,HIGH);
    client.stop();
    client.connect("prosismic.zeke.cl",80);
    Serial.println(" Connected to Prosismc ");

  }
  else {
    if (client.available()) {
      char c = client.read();
      // Serial.write(c);
    }
    digitalWrite(ServerPin,LOW);
  }


  led_display();


  digitalWrite(LED_BUILTIN,toggle);
  digitalWrite(EventPin,eventtoggle);
  digitalWrite(StatusPin,statustoggle);


  if ((Time.now() - tc_reset) >= (RestartTime)) {
    Serial.print(" Reinicio de variables ");
    tc_reset = Time.now();

    if (!EVENT) {
      // if (FILTER == false)
      //  offset(N_OFFSET);
      // t_eventoled = 0;

      c_muestra = 0;

      EVENT = false;
      CSERVER = true;
      DATASEND = false;
      MCHECK = false;
      DPCHECK = false;
      REINICIO = true;
    }
  }

  /* Status send*/
  if ((Time.now() - t_online) >=  OnlineTime) {
    t_online = Time.now();
    sendStatus(1);
    Particle.publish("Online");

  }

}



int sendStatus(int _status) {
  /*
     1. Activo/Habilitado
     2. Activo/Inhibido
     3 .Activo/error de parametro
     4 ....
     5  ....
     4 y 5 por definir
   */
  char line[60];
  snprintf(line, sizeof(line), "%s;%lu;%d",id, Time.now(),_status);
  Serial.println(line);
  request.hostname = "prosismic.zeke.cl";
  request.path = "/registrarEstado";
  request.body = String(line);
  http.post(request, response, headers);
  return 0;
}

int led_display(){

  if (EVENT == true){
    toggle = true;
    statustoggle = false; // check
    eventtoggle = !eventtoggle;  // check
    return 0;
  }

  else { // EVENT == false

    /* led event display*/
    if(((Time.now()-t_eventoled) < 7*SEGUNDOS_POR_MINUTO) && DATASEND == true){
      /* update every 0.5 secs */

      if((millis()-t_millis) >= 500)
        statustoggle = false;


      else
        statustoggle = true;

    }

    return 1;

  }

}


// se guarda la latitude y longitud
void locationCallback(float lat, float lon, float accuracy) {
  String(lat).toCharArray(latitude, 32);
  String(lon).toCharArray(longitude, 32);

}

// Se reinician los valores iniciales, se ajusta el offset y se calculan las
// referencias.

bool reiniciando() {

  time_t tiempo = (RestartTime) - (Time.now()  - tc_reset);

  if(tiempo % 60 == 0){
    Serial.print(" t_reset ");
    Serial.print(tiempo / 60);
    Serial.print("(min) ");
  }

  if (( REINICIO == true ) && (X.size() >= SAMPLES)) {

    if (REFERENCIA_VARIABLE  == true ){ // solo se modifica al inicio

      if( CalcRef(tc_referencia, SAMPLES * 5) == false ) { // está calculando
        DATASEND = false;
        REINICIO = true;
        tc_referencia++;
        return true;
      }
      else { // terminó el conteo para el calculo de la referencia
        DATASEND = true;
        REINICIO = false;
        tc_referencia = 0;
        client.stop();
        tc_dpcheck = 0;
        tc_mcheck = 0;
        tc_temp1 = 0;
        tc_temp2 = 0;
        tc_mcheck = 0;
        ce_mcheck = 0;
        return false;
      }

    }


    else { // REFERNCIA_VARIABLE = false
      // usar parametros variables por particle
      Serial.print("Referencia Fija");
      IQRref = 500;   // [mg] integer
      CAVref = 1000;  // [mg] integer
      RSLref = 300;   // percent para medir la ligua
      ZCref = 22;
      DATASEND = true;
      REINICIO = false;
      client.stop();
      c_muestra = 0;
      tc_dpcheck = 0;
      tc_mcheck = 0;
      tc_temp1 = 0;
      tc_temp2 = 0;
      tc_mcheck = 0;
      ce_mcheck = 0;
      Serial.print(" ");
      return false;
    }

  }  // fin del calculo de las referencias

  return false;
}


// avisa cuando un evento no es notificado al servidor
int evento_sin_conexion() {
  if (!CSERVER) {  // wait for server resend
    Serial.print("Pause event for ");
    Serial.print(SAMPLES / 2 - tc_cserver);
    Serial.print(" ce_cserver");
    Serial.print(" ");
    tc_cserver++;

    /* check server count complete */
    if (tc_cserver >= SAMPLES / 2) {
      tc_cserver = 0;
      DATASEND = true;
      CSERVER = true;
    }
    return 1;
  }
  return 0;
}





// revisa si hay eventos conseuctivos y detiene el envío de eventos en caso
// afirmativo
int control_de_eventos_consecutivos() {
  if (EVENT) {  // pause after eventis detected

    /* check if event count comp	// Initialize sensor
       LIS3DHConfig config;
       config.setAccelMode(LIS3DH::RATE_100_HZ);lete */
    if (ce_event >= SAMPLES / 2) {
      ce_event = 0;
      DATASEND = true;
      EVENT = false;
    } else {
      Serial.print("Pause for ");
      Serial.print(SAMPLES / 2 - ce_event);
      Serial.print(" ce_event");
      Serial.print(" ");
      ce_event++;
    }
    return 1;
  }
  return 0;
}





// revisa si hay desplazamiento del sensor
int antidesplazamiento() {
  if (DPCHECK == true) {
    char dpline[100];

    if (tc_dpcheck <= DPTIME) {  // check 6000 count windwow
      snprintf(dpline, sizeof(dpline),"PDEvent %d/3 in %4d count - ec1 %d ec2 %d", 
          ce_dpcheck, DPTIME - tc_dpcheck, tc_temp1, tc_temp2);
      Serial.print(dpline);
      Serial.print(" ");


      if (ce_dpcheck == 1) {
        tc_temp1++;
      }

      if (ce_dpcheck == 2) {
        if (tc_temp1 >= 300) {
          tc_temp2++;
        } else {
          tc_temp1 = 0;
          ce_dpcheck = 1;
        }
      }

      if (ce_dpcheck == 3) {
        if (tc_temp2 >= 300) {
          tc_dpcheck = 0;
          ce_dpcheck = 0;
          tc_dpchecktmp = 0;
          DATASEND = false;
          EVENT = false;
          DPCHECK = false;
          MCHECK = false;
          Serial.print(" Pause event sending until offset");
          Serial.print(" ");
        } else {
          tc_temp1 = 0;
          tc_temp2 = 0;
          ce_dpcheck = 1;
        }
      }
    }

    else {
      tc_dpcheck = 0;
      ce_dpcheck = 0;
      tc_dpchecktmp = 0;
      DPCHECK = false;
    }

    tc_dpcheck++;
    return 1;
  }
  return 0;
}




// revisa si hay movimiento duerante muestras


int antimovimiento() {
  char line[150];
  if (MCHECK == true) {
    if (tc_mcheck <= MTIME) {  // check 1500 count
      snprintf(line, sizeof(line), "MEvent %d/5 in %d count", ce_mcheck,
          (DPTIME - tc_mcheck));
      Serial.print(line);
      Serial.print(" ");
      tc_mcheck++;

      if (ce_mcheck >= 5) {  // are 5 event
        DATASEND = false;
        EVENT = false;
        MCHECK = false;
        DPCHECK = false;
        ce_event = 0;  // ready for next eventsamples
        Serial.print("Pause event sending until offset");
        Serial.print(" ");
      }
    }

    else {
      tc_mcheck = 0;
      ce_mcheck = 0;
      if (EVENT == false) MCHECK = false;
    }
    return 1;
  }

  return 0;
}

// Calculo de las referencias según los valores maximos y mininmos de las
// _samples muestras}


bool CalcRef(int _i, int _samples) {
  char line[80];

  if (_i < _samples) {  // numero de muestras para el calculo

    if (_i < 400) {  // las primeras 400 muestras son de estabilización

      IQRmax = -1;
      IQRmin = 9999999;
      ZCmax = -1;
      ZCmin = 32767;
      CAVmax = -1;
      CAVmin = 9999999;
      RSLmax = -1;
      RSLmin = 32767;

      Serial.print("Sensor stabilizing for ");
      Serial.print(_i);
      Serial.print(" count");

    }

    else {  // las siguientes muestras para buscar el máximo y mínimo

      if (IQR > IQRmax) {
        IQRmax = IQR;
      }
      if (IQR <= IQRmin) {
        IQRmin = IQR;
      }

      if (ZC > ZCmax) {
        ZCmax = ZC;
      }
      if (ZC <= ZCmin) {
        ZCmin = ZC;
      }

      if (CAV > CAVmax) {
        CAVmax = CAV;
      }
      if (CAV <= CAVmin) {
        CAVmin = CAV;
      }

      if (RSL > RSLmax) {
        RSLmax = RSL;
      }
      if (RSL <= RSLmin) {
        RSLmin = RSL;
      }

      Serial.print("Max/Min setting for ");
      Serial.print(_i);
      Serial.print(" count");
      /* Calculates de references each time for debug */
      IQRref = maxx(long(300), (IQRmax - IQRmin) * Factor_IQR);
      CAVref = maxx(long(500), (CAVmax - CAVmin) * Factor_CAV);
      ZCref = float((ZCmax + ZCmin) / 2) - float((ZCmax - ZCmin) * Factor_ZC);
      RSLref = maxx(155, (RSLmax - RSLmin) * Factor_RSL);
    }


    // muestra los valores estabilizados y los máximos y mínimos
    snprintf(line, sizeof(line), " %d %d %ld %ld %ld %ld %d %d", ZCmax,
        ZCmin, IQRmax, IQRmin, CAVmax, CAVmin, RSLmax, RSLmin);
    Serial.print(line);
    return false;  // sigue calculando
  }
  else { // se terminan las muestras

    Serial.print("References Calculated");
    Serial.print(" ");

    return true; // terminó el conteo de las muestras
  }
}

const short maxx(const short& a, const short& b) { return (a < b) ? b : a; }
const long maxx(const long& a, const long& b) { return (a < b) ? b : a; }
const int maxx(const int& a, const int& b) { return (a < b) ? b : a; }

int i = 0;


// Envía un evento al cloud de particle con la información del sismo.
int sendParticle() {
  char line[100];
  snprintf(line, sizeof(line),
      "%lu;%ld;%hd;%d;%ld;%ld;%d;%s;%s",
      (millis()-t_millis)%1000, ACNmax, trigger,ZC,IQR, CAV,RSL, latitude, longitude);
  Particle.publish("Sismo",line);
  EVENT = true;

  return 0;
}

// envía un post al servidor de prosismoc con la información del sismo
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

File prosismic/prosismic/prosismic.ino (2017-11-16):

#include <WifiLocation.h>
//#include <Arduino.h>
#include <ESP8266WiFi.h>
#include <WiFiUdp.h>
#include <TimeLib.h>

#include <Wire.h>
#include <LSM303.h>
#include <ADXL345.h>
#include <SparkFun_MMA8452Q.h>
#include <ESP8266HTTPClient.h>
//#include <ArduinoJson.h>

#include <DNSServer.h>            //Local DNS Server used for redirecting all requests to the configuration portal
#include <ESP8266WebServer.h>     //Local WebServer used to serve the configuration portal
#include <WiFiManager.h>          //https://github.com/tzapu/WiFiManager WiFi Configuration Magic
#include "vector.h"
#include <iterator>
#include <algorithm>    // std::sort
#include <Filters.h>    // test signal frequency (Hz) pmcFilter
bool myfunction (long i,long j) { return (i<j); }

#define N_OFFSET 32
#define SAMPLES 200           // samples number
#define N_WIN 2               // Windwos

#define TRNM 1UL             // Parameter in between windwos time in hour
#define T_OFFSET 10          // offset recalculation in minutes
#define T_STATUS    2        // time of status hrs
#define TST 10000UL          // Start parameter windwos in secs
#define TRNS 40              // Sample windows time in millisecs
#define TASD 1000            // time after send data in msecs
#define TWC 1                // time Wifi check
#define Factor_IQR  5.0      // Interquarile reference factor
#define Factor_CAV  1.5      // Cumulative acelerator vector reference factor
#define Factor_ZC   1        // Zero Crossing rate reference factor
#define Factor_RSL  3.5
#define StartWindow 20
#define _SSID "zekefi-interno"  // network name
#define _NETPASS "JtXDF5jK79es" // network password
#define OFFSET true              // set median dc offset remove
#define REF_VAR  false          // indicate if reference are variables or fixed values

#define LSMACC   1          // LSM303 acceleromter ID
#define MMAACC   2          // MMA8452Q acceleromter ID
#define ADXLACC  3          // ADXL345 acceleromter ID
byte acc_id;                // accelerometer identification

int EventPin = D7;     // wifi status LED
int StatusPin = D6;      // accelerometer data readings LED
int ButtonPin = D3;   // On/Off wifi settings

/* Sampling freq */
#define FrecRPS  100                   // Tasa de muestreo definida por el usuario (100 a 200)
unsigned int INTERVALO = (1000 / FrecRPS); // s

/* time variables */
time_t tiempo;        // ?
time_t prevtime;      // time for check every one second
time_t t_offsetlap;   // time between offset recalculation
time_t t_mevent;      // when an event start && movement timer checker
time_t t_dpevent;      // when an event start && displacement timer checker
time_t t_temp;         // temporal for DP event
time_t wifiLap;       // counter time for wifi check
time_t ntpmicro;      // ntp microseconds
time_t eventAccion;   // time after event is on
time_t amaxm;         // millsecond of the max acceleration
time_t t_online;      //
time_t t_eventled;    // timer for led event display



/* accelerometer parameters and variables  */
char ID[15];                  // device number identification

// status variables
bool ISCALC;                  // parameter calculation enable/disable
bool EVENT;                   // event detection on/off
bool REFERENCE;               // parameter calculation event
bool CSERVER;                 // check if central server is responding on/off
bool DATASEND;                // enable/disable send event to server
bool MCHECK;                  // movement event checker
bool DPCHECK;                  // displacement event checker
bool ISAFULL;                  // Check if array samples are full true = full
bool REPORT;                    // report status device
bool FILTER;                    // ENABLE DISABLE FILTER
bool WIFIRST;                  // wifi reset


// variabales counters per samples
int psample;                   // sample counter for parameters calculation
int s_cserver;                 // samples counter when server is not responding
int sample;                    // sample index
int c_mevent;                  // movement event counter
int c_pdevent;                 // prolongate seism and displacement for 0: counter / 1: time seims event counter
int eventsample;               // samples after first event detected

// timer counters
int tc_mevent;                 // cunter for an event start && movement checker
int tc_pdevent;                // for event start && displacement checker
int tc_temp1;                   // counter temporal for PD event
int tc_temp2;                   // counter temporal for PD event
int tc_wifirst;                // counter for  wifi rst button

//acelerometer objets
LSM303 compass;               // acelerometer objet
MMA8452Q accel;
ADXL345 accelerometer;
Vector sca;

// acceleromter variables

long offset_x, offset_y, offset_z;         // offset data for normalization
short old_x, old_y, old_z;                 // old acceleration data for normalization
long AccNetnow[SAMPLES];                   // net acceleration
short acc_x[SAMPLES];                      // xyz axis acceleration array
short acc_y[SAMPLES];                      // xyz axis acceleration array
short acc_z[SAMPLES];                      // xyz axis acceleration array
short acc_xMax, acc_yMax, acc_zMax;        // xyzaxis max acceleration
short mag_t;                               // sample number of aceleration magnitude

etl::vector<short,SAMPLES> X;
etl::vector<short,SAMPLES> Y;
etl::vector<short,SAMPLES> Z;
etl::vector<long,SAMPLES> XYZ;

float testFrequency = 2;                     // test signal frequency (Hz)
FilterOnePole filterOneHighpassX( HIGHPASS, testFrequency );  // create a one pole (RC) highpass filter pmcFilter
FilterOnePole filterOneHighpassY( HIGHPASS, testFrequency );  // create a one pole (RC) highpass filter pmcFilter
FilterOnePole filterOneHighpassZ( HIGHPASS, testFrequency );  // create a one pole (RC) highpass filter pmcFilter

// Parameter variables
long  ACNmax, ACNmin;               // Max net acceleration
short RSL, RSLref, RSLmin, RSLmax;    // Mr. P parameter value
long IQR, IQRref, IQRmin, IQRmax;    // Interquiarlie Values
short ZC, ZCref, ZCmax, ZCmin;     //  Zero crossing
long CAV, CAVref, CAVmax, CAVmin;    // Cumulative Acceleration Value

short trigger;                 // 0:notrigger / 1:RSL / 2:ZIC

/* AP settings */
char ssid[] = _SSID;           //  your network SSID (name)
char pass[] = _NETPASS;       // your network password
WiFiManager wifiManager;


/* NTP parameters and NTP Servers: */
//static const char ntpServerName[] = "us.pool.ntp.org";
char ntpServerName[40];
WiFiUDP Udp;
unsigned int localPort = 8888;  // local port to listen for UDP packets
const unsigned long HTTP_TIMEOUT = 10000;  // max respone time from server
const size_t MAX_CONTENT_SIZE = 512;       // max size of the HTTP response
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

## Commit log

2017-05-19 Stable Version. Check the HP filter
2017-05-19 Stable version. Chek HP filter
2017-06-29 First hardware ever
    [prosismic.brd, prosismic.sch]
2017-07-03 time fixed ... still missing time sync with Partcile Cloud
    [prosismic.ino]
2017-07-28 fixed datasend on starup. First stable version
    [prosismic.ino]
2017-07-31 first version of the enclosure
    [tapadelantera.dxf, tapaslaterales.dxf, tapatrasera.dxf]
2017-08-04 add x-axis and parameters plotter
2017-08-04 no se que decir
2017-08-07 add filter
2017-08-21 big case
    [#tapas.dxf, laterales.dxf, tapas.dxf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]
2017-08-21 add filter library
2017-08-21 add status led display
2017-08-22 led update
2017-08-28 new version
    [laterales.dxf, tapas.dxf]
2017-08-28 add new status server. finish version 3 case
    [#tapas.dxf, Qup-Logo.dxf, laterales.dxf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]
2017-08-30 agregue versión 4
    [#tapasv44.dxf, tapasv4.dxf]
2017-08-31 agregé cambie el nombre de la pagina del servidor web y una arreglé las luces del comienzo.
    [prosismic.ino]
2017-09-07 se arregla el aviso de estado
    [prosismic.ino]
2017-09-07 nuevas tapas
    [#tapasv5.dxf, lateralesv5.dxf, tapasolav4.dxf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]
2017-10-31 agregue librerias
    [prosismic.brd, prosismic.sch]
2017-10-31 modificacion de librerias
2017-10-31 para dejar fuera archivos de eagle
2017-10-31 arreglo de librerias
2017-11-06 agregue wire.h para que funciora la libreria del acelerometro
2017-11-09 revisar la conexión al servidor
2017-11-12 actualizacion de prosismic
2017-11-14 listo la modificación de variables y conexión con el server
2017-11-15 arreglo de Google maps
    [q_up.ino]
2017-11-17 agregué libreria Filter y organicé funciones

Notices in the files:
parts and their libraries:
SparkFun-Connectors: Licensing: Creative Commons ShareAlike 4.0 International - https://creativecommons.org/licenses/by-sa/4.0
